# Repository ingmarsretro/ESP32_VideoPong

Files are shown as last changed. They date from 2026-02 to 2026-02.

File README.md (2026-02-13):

<p align="center">
  Vectorgameboard Video Pong
</p>

# ESP32 PAL Pong - Vectorgameboard V1.0

Dieses Projekt ist eine klassische Pong-Umsetzung für den **ESP32**, die ein echtes **PAL-Videosignal** (Composite/FBAS) direkt über einen GPIO erzeugt. Ursprünglich als Demonstration für einen FH-Tag entwickelt, nutzt der Code das volle Potenzial des eigens dafür entwickelten **Vectorgameboards**.

## 🚀 Das Vectorgameboard V1.0
Passend zu dieser Software wurde eine dedizierte Platine entwickelt, die den ESP32 aufnimmt und alle notwendigen Komponenten "on-board" vereint:

*   **All-in-One Design:** Integrierte Potentiometer, Taster sowie Buchsen für Video- und Audio-Out.
*   **Audio-System:** Ein kleiner Lautsprecher samt Verstärker ist direkt auf dem Board verbaut.
*   **Dual-Mode Hardware:** Das Board ist sowohl für Composite-Video (PAL/NTSC) als auch für **ESP Vector Software** (X-Y-Modus für Oszilloskope) ausgelegt.
*   **Externer DAC:** Für die hochpräzise Vektordarstellung ist ein externer DAC verbaut.
*   **Open Hardware:** Details zu den Verbindungen, der Bestückung und dem Design finden sich in den **Schaltplänen** und **Eagle-Layouts** in diesem Repository.

## 📺 Software-Features
*   **PAL-Ausgabe:** Erzeugung eines Composite-Signals auf **PIN 25**.
*   **Spielmodi:** Wahl zwischen Singleplayer (gegen KI) und lokalem Multiplayer (1vs1).
*   **Steuerung:** Analoges Paddle-Feeling durch die Nutzung der On-Board Potentiometer.
*   **Grafik:** Integration von Bitmaps (Avatar/Logo) und Text via Bitluni-Library.
*   **Sound:** Akustisches Feedback bei Ballkontakt, Punktgewinn und Spielende.

## ⚠️ Wichtige Kompilier-Hinweise
Da die Video-Generierung extrem zeitkritisch ist, müssen zwingend folgende Library-Versionen verwendet werden. **Versionen der 3.x.x Schiene sind aktuell nicht kompatibel!**

| Komponente | Version |
| :--- | :--- |
| **ESP32 by Espressif Systems** | `2.0.0` |
| **Arduino ESP32 Boards** | `2.0.11` |
| **bitluni ESP32Lib** | `0.3.1` |

*Hinweis: Beim Kompilieren auftretende Warnungen können ignoriert werden.*

## 🛠 Hardware-Belegung (Pinout)
| Komponente | GPIO | Beschreibung |
| :--- | :--- | :--- |
| **Video Out** | 25 | Composite Signal |
| **Buzzer/Audio** | 27 | Soundausgabe (interner Verstärker) |
| **Poti 1** | 35 | Player 1 (Links) |
| **Poti 2** | 34 | Player 2 (Rechts) |
| **Button 1** | 32 | Modus wechseln |
| **Button 2** | 33 | Start / Aktion |

## 📜 Credits
*   **Hardware & Software:** ingmarsretro (Stand: Feb. 2026)
*   **Video Library:** Ein Dank geht an [bitluni](https://github.com) für die Bereitstellung der `ESP32Lib`.

---
*Viel Spaß beim Retrogaming auf dem Oszilloskop oder Röhrenfernseher!*

# ESP32 PAL Pong - Vectorgameboard V1.0

This project is a classic Pong implementation for the **ESP32**, generating a real **PAL composite video signal** (FBAS) directly via GPIO. originally developed as a demonstration for a university tech-day, this code utilizes the full potential of the custom-designed **Vectorgameboard**.

## 🚀 The Vectorgameboard V1.0
To support this software, a dedicated PCB was developed that houses the ESP32 and integrates all necessary components on-board:

*   **All-in-One Design:** Includes on-board potentiometers, buttons, and dedicated jacks for Video and Audio Out.
*   **Audio System:** Features a built-in small speaker and an integrated amplifier for immediate sound feedback.
*   **Dual-Mode Hardware:** The board is designed for both Composite Video (PAL/NTSC) and **ESP Vector Software** (X-Y mode for oscilloscopes).
*   **External DAC:** A dedicated external DAC is included for high-precision vector rendering on analog screens.
*   **Open Hardware:** Detailed schematics and **Eagle layouts** are available within this repository.

## 📺 Software Features
*   **PAL Output:** Generates a composite signal on **PIN 25**.
*   **Game Modes:** Toggle between Singleplayer (vs. AI) and local Multiplayer (1vs1).
*   **Precision Control:** Authentic analog paddle feeling using the on-board potentiometers.
*   **Graphics:** Integration of custom bitmaps (avatar/logo) and text overlays via the Bitluni library.
*   **Sound:** Haptic audio feedback for ball collisions, scoring, and game-over states.

## ⚠️ Critical Compilation Notes
Video generation on the ESP32 is extremely time-sensitive. To compile successfully, you **must** use the following library versions. **Versions 3.x.x are currently not compatible!**

| Component | Version |
| :--- | :--- |
| **ESP32 by Espressif Systems** | `2.0.0` |
| **Arduino ESP32 Boards** | `2.0.11` |
| **bitluni ESP32Lib** | `0.3.1` |

*Note: You can safely ignore compiler warnings during the build process.*

## 🛠 Hardware Pinout
| Component | GPIO | Description |
| :--- | :--- | :--- |
| **Video Out** | 25 | Composite Signal |
| **Buzzer/Audio** | 27 | Audio Output (Internal Amp) |
| **Pot 1** | 35 | Player 1 (Left) |
| **Pot 2** | 34 | Player 2 (Right) |
| **Button 1** | 32 | Change Mode |
| **Button 2** | 33 | Start / Action |

## 📜 Credits
*   **Hardware & Software:** ingmarsretro (Released: Feb. 2026)
*   **Video Library:** Special thanks to [bitluni](https://github.com) for the excellent `ESP32Lib`.

---
*Have fun retrogaming on your CRT TV or Oscilloscope!*

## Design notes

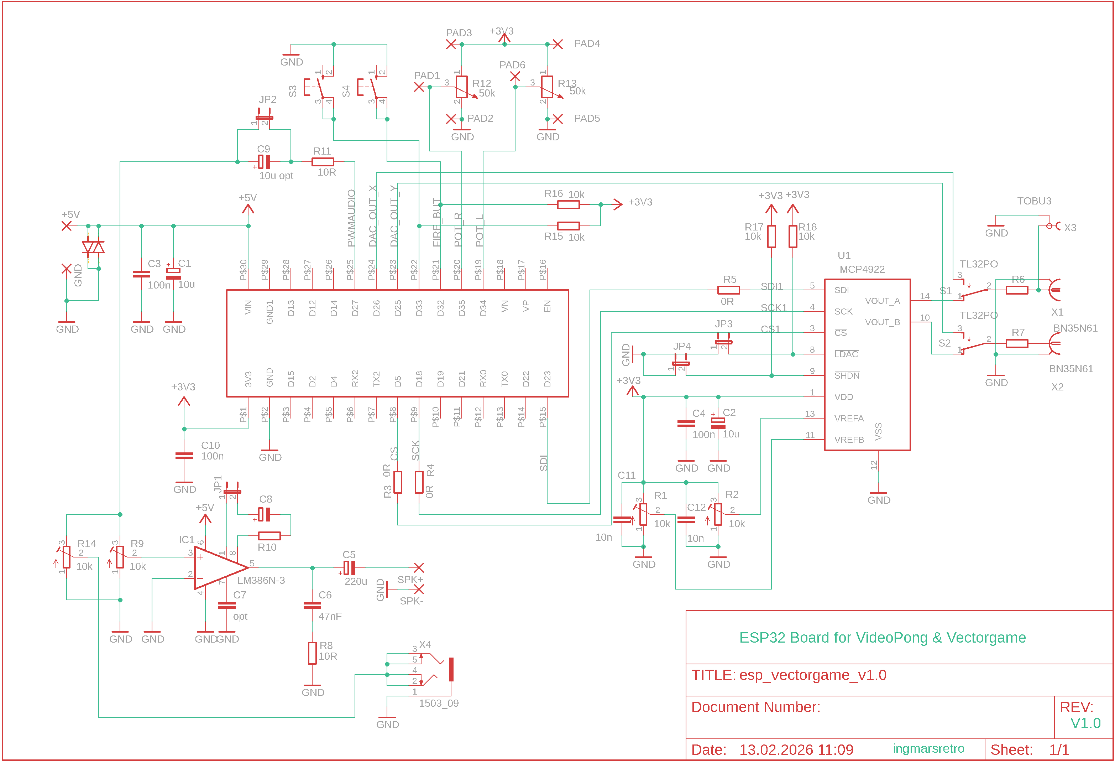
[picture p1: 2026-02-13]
PCB/schematic_v1.0.png

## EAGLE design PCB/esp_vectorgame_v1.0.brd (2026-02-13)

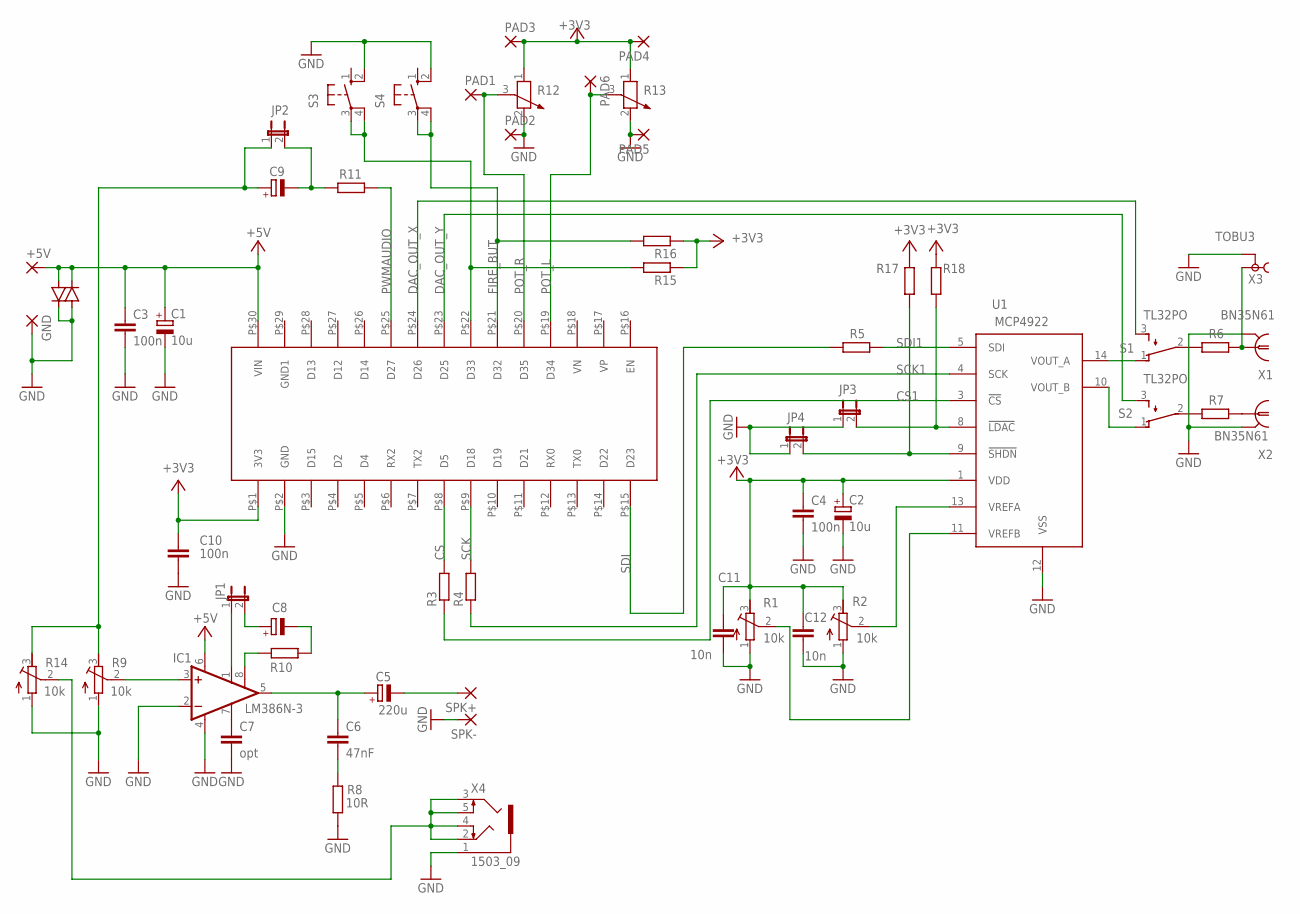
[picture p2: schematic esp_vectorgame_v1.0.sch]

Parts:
+5V: 3,81/1,4
C1, C2: 10u; E2,5-6E
C3, C4, C10: 100n; C0805
C5: 220u; E2,5-6E
C6: 47nF; C0805
C7: opt; C0805
C8, C9: CPOL-EUE2,5-6E; E2,5-6E
C11, C12: 10n; C0805
GND: 3,81/1,4
IC1: LM386N-3; DIL08
JP1, JP2, JP3, JP4: JP1E; JP1
PAD1, PAD2, PAD3, PAD4, PAD5, PAD6: 3,81/1,4
R1, R2, R9, R14: 10k; RTRIM64W
R3, R4, R5, R6, R7, R10, R11, R15, R16, R17, R18: R-EU_R0805; R0805
R8: 10R; R0805
R12, R13: POTENTIOMETER_PT-10; PT-10
S1, S2: TL32PO; TL3XPO
S3, S4: 10-XX; B3F-10XX
SPK+: 3,81/1,4
SPK-: 3,81/1,4
TVS1, TVS2: 1N4148DO35-7; DO35-7
U1: MCP4922; SO-14
U$2: ESP_WROOM32; ESP_NODEMCU
X1, X2: BN35N61; B35N61
X3: TOBU3
X4: 1503_09

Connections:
+3V3: C2.+, C4.1, C10.1, C11.1, C12.1, PAD3.1, PAD4.1, R1.3 (E), R2.3 (E), R12.1, R13.1, R15.1, R16.1, R17.1, R18.1, U1.1 (VDD), U$2.P$1 (3V3)
+5V: +5V.1, C1.+, C3.1, IC1.6 (VS), TVS1.C, TVS2.A, U$2.P$30 (VIN)
CS: R3.2, U$2.P$8 (D5)
CS1: R3.1, U1.3 (!CS)
DAC_OUT_X: S1.3 (S), U$2.P$24 (D26)
DAC_OUT_Y: S2.3 (S), U$2.P$23 (D25)
FIRE_BUT: R16.2, S4.3, S4.4 (P1), U$2.P$21 (D32)
GND: C1.-, C2.-, C3.2, C4.2, C7.2, C10.2, C11.2, C12.2, GND.1, IC1.2 (-IN), IC1.4 (GND), JP3.1, JP4.1, PAD2.1, PAD5.1, R1.1 (A), R2.1 (A), R8.1, R9.1 (A), R12.2, R13.2, R14.1 (A), S3.2 (S1), S4.2 (S1), SPK-.1, TVS1.A, TVS2.C, U1.12 (VSS), U$2.P$2 (GND), X1.2, X1.3 (2), X1.4 (2), X1.5 (2), X2.2, X2.3 (2), X2.4 (2), X2.5 (2), X3.2, X3.2@1 (2), X3.2@2 (2), X4.1
unnamed: JP3.2, R18.2, U1.8 (!LDAC)
unnamed: R7.1, X2.1
unnamed: R7.2, S2.2
unnamed: S1.1 (O), U1.14 (VOUT_A)
unnamed: R1.2 (S), U1.11 (VREFB)
unnamed: R2.2 (S), U1.13 (VREFA)
unnamed: S2.1 (O), U1.10 (VOUT_B)
unnamed: R6.1, X1.1, X3.1
unnamed: R6.2, S1.2
unnamed: C6.2, R8.2
unnamed: IC1.1 (GAIN), JP1.1
unnamed: C5.+, C6.1, IC1.5 (OUT)
unnamed: C7.1, IC1.7 (BYPASS)
unnamed: IC1.3 (+IN), R9.2 (S)
unnamed: C8.+, JP1.2
unnamed: IC1.8 (GAIN), R10.2
unnamed: C8.-, R10.1
unnamed: C9.-, JP2.2, R11.2
unnamed: C9.+, JP2.1, R9.3 (E), R14.3 (E)
unnamed: R14.2 (S), X4.2, X4.3, X4.4, X4.5
unnamed: C5.-, SPK+.1
unnamed: R15.2, S3.3, S3.4 (P1), U$2.P$22 (D33)
unnamed: JP4.2, R17.2, U1.9 (!SHDN)
POT_L: PAD6.1, R13.3, U$2.P$19 (D34)
POT_R: PAD1.1, R12.3, U$2.P$20 (D35)
PWMAUDIO: R11.1, U$2.P$25 (D27)
SCK: R4.2, U$2.P$9 (D18)
SCK1: R4.1, U1.4 (SCK)
SDI: R5.2, U$2.P$15 (D23)
SDI1: R5.1, U1.5 (SDI)

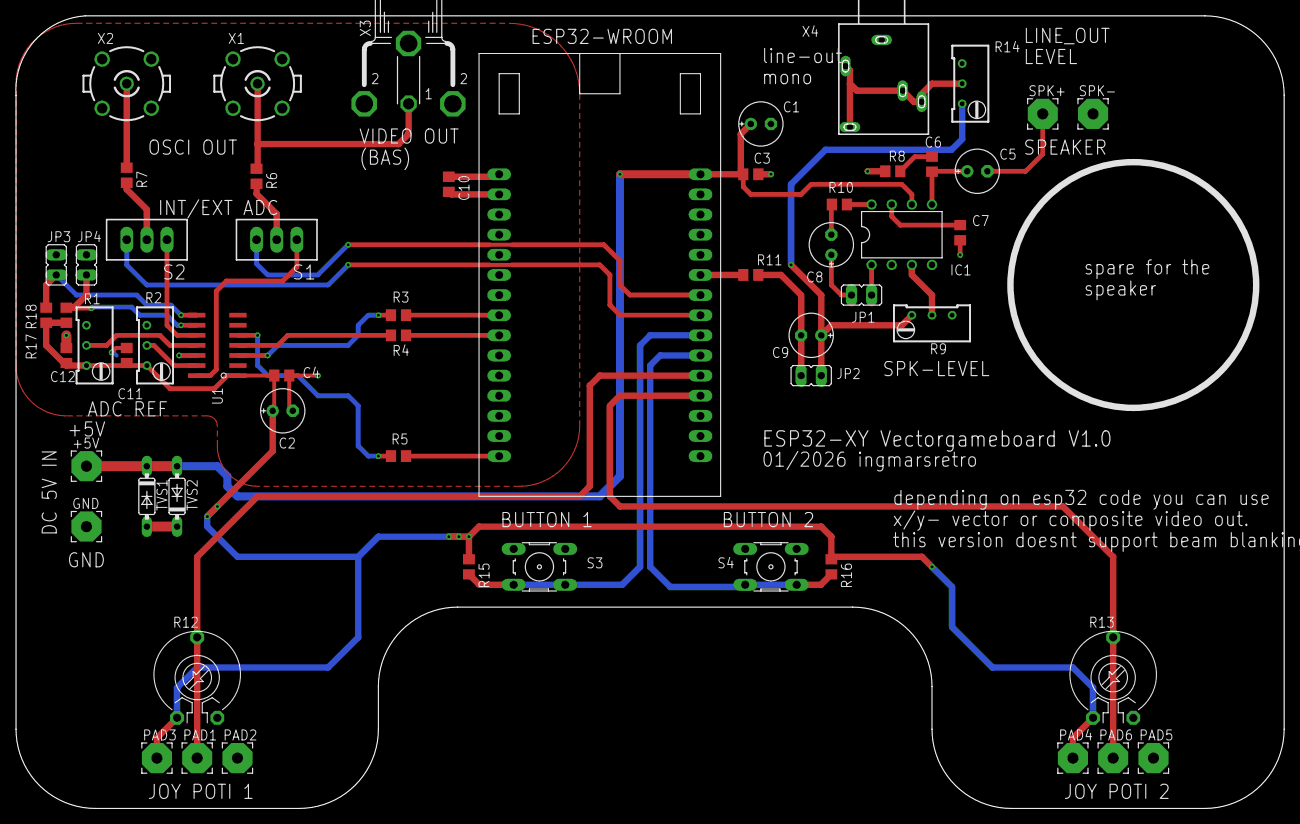
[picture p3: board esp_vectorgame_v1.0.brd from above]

Board: 2 copper layers, 160.0 x 100.0 mm, 57 parts (0 on the bottom side), 38 nets.

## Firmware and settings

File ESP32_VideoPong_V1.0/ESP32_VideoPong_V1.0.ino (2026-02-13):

// ESP32 PAL Videogame for Vectorgameboard V1.0
// Softwareversion V1 beta by ingmarsretro Feb.2026
// Videolibrary from: BITLUNI thanks for the great work
// the esp-32 controller generates composite videosignal on PIN25

// this code was written for a demonstration at the fh-day
// the ESPBoard i used is ESP32 WROOM board
// in the IDE select "ESP32 Dev Module"  240MHz, PSRAM disabled,
// but i will it go on with it ... 

// important; to successfully compile the code you need library verions:
// you can ignore the warnings
// esp32 by Espressif Systems  2.0.0 (not compatible with 3.x.x)
// Arduino ESP32 Boards 2.0.11
// bitluni ESP32Lib 0.3.1

#include "esp_pm.h"
#include "CompositeGraphics.h"
#include "CompositeOutput.h"
#include "Image.h"
#include "avatar.h" 
#include "font6x8.h"
#include <soc/rtc.h>

// --- PINASSIGNMENT ---
const int BUZZER_PIN = 27; 
const int BUTTON_PIN = 32;  // Modus wechseln
const int BUTTON_PIN2 = 33; // Start / Aktion
const int POTI_PIN = 35;    // Poti Player 1 (Links)
const int POTI_PIN2 = 34;   // Poti Player 2 (Rechts)

// --- KONSTANTEN ---
const int XRES = 324;
const int YRES = 268;

enum State { START, PLAYING, WON };
State gameState = START;
bool twoPlayerMode = false;

CompositeGraphics graphics(XRES, YRES);
CompositeOutput composite(CompositeOutput::PAL, XRES * 2, YRES * 2);
Font<CompositeGraphics> font(6, 8, font6x8::pixels);
Image<CompositeGraphics> avatar0(avatar::xres, avatar::yres, avatar::pixels);

float ballX = XRES / 2, ballY = YRES / 2;
float ballDX = 2.5, ballDY = 1.8;
int ballSize = 8;
int paddleW = 6, paddleH = 40;

float paddle1Y = YRES / 2 - 20;
float paddle2Y = YRES / 2 - 20;
int score1 = 0, score2 = 0;

void esp32_tone(int freq, int duration) {
  ledcSetup(0, freq, 10);
  ledcAttachPin(BUZZER_PIN, 0);
  ledcWriteTone(0, freq);
  delay(duration);
  ledcWriteTone(0, 0);
}

void playSound(int type) {
  switch(type) {
    case 1: esp32_tone(1000, 30); break; 
    case 2: esp32_tone(150, 400); break; 
    case 3: esp32_tone(800, 200); break; 
  }
}

void setup() {
  pinMode(BUZZER_PIN, OUTPUT);
  pinMode(BUTTON_PIN, INPUT_PULLUP);
  pinMode(BUTTON_PIN2, INPUT_PULLUP);
  
  esp_pm_lock_handle_t powerManagementLock;
  esp_pm_lock_create(ESP_PM_CPU_FREQ_MAX, 0, "compositeCorePerformanceLock", &powerManagementLock);
  esp_pm_lock_acquire(powerManagementLock);

  composite.init();
  graphics.init();
  graphics.setFont(font);
  xTaskCreatePinnedToCore(compositeCore, "compositeCoreTask", 2048, NULL, 1, NULL, 0);
}

void compositeCore(void *data) {
  while (true) {
    composite.sendFrameHalfResolution(&graphics.frame);
  }
}

void updatePhysics() {
  paddle1Y = (analogRead(POTI_PIN) / 4095.0) * (YRES - paddleH);
  if (twoPlayerMode) {
    paddle2Y = (analogRead(POTI_PIN2) / 4095.0) * (YRES - paddleH);
  } else {
    float target = ballY - (paddleH / 2);
    paddle2Y += (target - paddle2Y) * 0.15; 
  }
  ballX += ballDX;
  ballY += ballDY;
  if (ballY <= 0 || ballY >= YRES - ballSize) ballDY *= -1;
  if (ballX <= 15 + paddleW && ballX >= 15) {
    if (ballY + ballSize >= paddle1Y && ballY <= paddle1Y + paddleH) {
      ballDX = abs(ballDX) * 1.05; 
      ballX = 15 + paddleW + 1;
      playSound(1);
    }
  }
  if (ballX >= XRES - 15 - paddleW - ballSize && ballX <= XRES - 15) {
    if (ballY + ballSize >= paddle2Y && ballY <= paddle2Y + paddleH) {
      ballDX = -abs(ballDX) * 1.05;
      ballX = XRES - 15 - paddleW - ballSize - 1;
      playSound(1);
    }
  }
  if (ballX < 0) { score2++; ballX = XRES/2; ballDX = 2.5; playSound(2); }
  if (ballX > XRES) { score1++; ballX = XRES/2; ballDX = -2.5; playSound(2); }
  if (score1 >= 10 || score2 >= 10) { gameState = WON; playSound(3); }
}

void drawStartScreen() {
  graphics.begin(0);
  graphics.setCursor(XRES / 2 - 55, 60);
  graphics.print((char*)"INGMARSRETRO VIDEO-PONG");
  graphics.setCursor(XRES / 2 - 65, 120);
  if (twoPlayerMode) graphics.print((char*)"SPIEL: SPIELER VS SPIELER");
  else               graphics.print((char*)"SPIEL: SPIELER VS COMPUTER");
  graphics.setCursor(XRES / 2 - 80, 180);
  graphics.print((char*)"BUTTON 2: SPIELMODUS");
  graphics.setCursor(XRES / 2 - 80, 190);
  graphics.print((char*)"BUTTON 1: START");
  graphics.end();
  if (digitalRead(BUTTON_PIN) == LOW) { twoPlayerMode = !twoPlayerMode; delay(250); }
  if (digitalRead(BUTTON_PIN2) == LOW) { score1 = 0; score2 = 0; gameState = PLAYING; delay(200); }
}

void drawGame() {
  graphics.begin(0);
  updatePhysics();
  graphics.setCursor(XRES / 2 - 30, 10);
  graphics.print(score1); 
  graphics.print((char*)" : "); 
  graphics.print(score2);
  graphics.fillRect(15, (int)paddle1Y, paddleW, paddleH, 50);
  graphics.fillRect(XRES - 15 - paddleW, (int)paddle2Y, paddleW, paddleH, 50);
  graphics.fillRect((int)ballX, (int)ballY, ballSize, ballSize, 63);
  for(int i=0; i<YRES; i+=15) graphics.line(XRES/2, i, XRES/2, i+7, 20);
  graphics.end();
}

void drawWinScreen() {
  graphics.begin(0);
  avatar0.draw(graphics, (XRES/2)-(avatar::xres/2), 0); // Bild "avatar" darstellen
  graphics.setCursor(XRES / 2 - 40, YRES - 10);
  
  // PRINT WINNER
  if (score1 >= 10) {
    graphics.print((char*)"PLAYER 1 SIEGT!");
  } else {
    graphics.print((char*)"PLAYER 2 SIEGT!");
  }
  
  graphics.setCursor(XRES / 2 - 50, YRES - 30);
  graphics.print((char*)"START NEUSTART");
  graphics.end();

  if (digitalRead(BUTTON_PIN2) == LOW) {
    gameState = START;
    delay(200);
  }
}

void loop() {
  switch (gameState) {
    case START:   drawStartScreen(); break;
    case PLAYING: drawGame();        break;
    case WON:     drawWinScreen();   break;
  }
}
